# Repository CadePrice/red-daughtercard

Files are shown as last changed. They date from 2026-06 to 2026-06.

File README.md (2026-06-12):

# teensy4.1-daughtercard

* Goal: Connect GigaPCB female connector (XG4H-5031) onto a Teensy 4.1 daughtercard.
* Solution: Use a male connector (XG4A-5034) to link GigaPCB to Teensy 4.1 MCU.

**ALL PLANNING INFORMATION AND PIN WORKS CAN BE FOUND HERE: https://docs.google.com/spreadsheets/d/1IKXbfIiIrP6nyM8Mc0eolMKgb26c2Qc9dl-_x0jVvCI/edit?usp=sharing**

Revisions after Design Review #1 (6/11)
* Added a 3v3 LED to indicate good board connection
* Made TX+/TX- and RX+/RX- differential pairs with matched lengths
* Added GND vias across the board
* Made it a four layer board (signals -> ground -> power -> signals)

Contains the daughtercard housing the Teensy4.1 MCU used for the GIGAPCB architecture for Texas A&amp;M Rocket Engine Design. An Standard Operating Procedure (SOP) will be provided for assembly/use instructions.

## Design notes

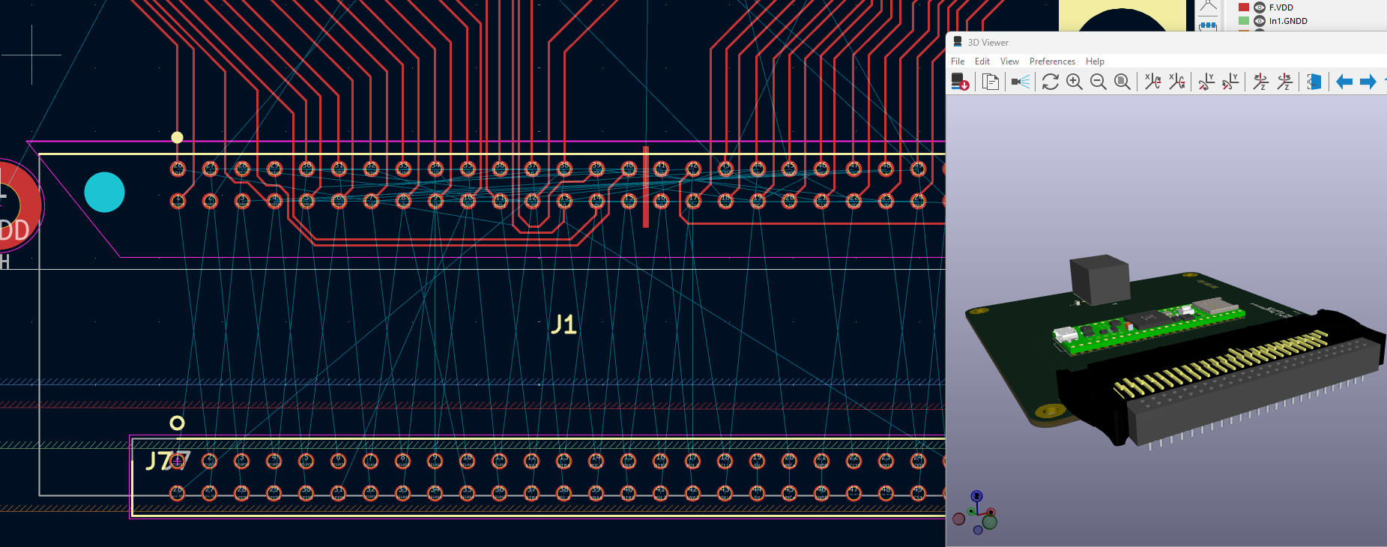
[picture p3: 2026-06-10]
docs/how the connectors will link.png

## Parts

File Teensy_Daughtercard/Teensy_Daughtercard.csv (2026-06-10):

Reference | Qty | Value | DNP | Exclude from BOM | Exclude from Board | Footprint | Datasheet | Mouser Part Number
C1 | 1 | 0.1uF |  |  |  | K104K15X7RF5TL2:K104K15X7RF5TL2 | https://componentsearchengine.com/Datasheets/1/K104K15X7RF5TL2.pdf | 594-K104K15X7RF5TL2
H1,H2,H3,H4 | 4 | MH |  | Excluded from BOM |  | MountingHole:MountingHole_3.5mm_Pad | ~
J1 | 1 | L77HDB44SD1CH4RSAG |  |  |  | L77HDB44SD1CH4RSAG:L77HDB44SD1CH4RSAG | https://componentsearchengine.com/Datasheets/1/L77HDB44SD1CH4RSAG.pdf | 523-L77HDB44SD1CH4RS
J2,J3 | 2 | Conn_01x24_Socket |  |  | Excluded from board |  | https://www.mouser.com/datasheet/3/71/1/M20_782.pdf | 855-M20-7823242
J4,J5 | 2 | Conn_01x24_Pin |  |  | Excluded from board |  | https://cdn.amphenol-cs.com/media/wysiwyg/files/drawing/68000.pdf | 649-68000-124HLF
J6 | 1 | LPJ4012AHNL |  |  |  | LPJ4012AHNL:LPJ4012AHNL | https://www.l-p.com/file/datasheet/lpj4012ahnl-drawing.pdf
U1 | 1 | Teensy4.1 |  |  |  | Teensy:Teensy41

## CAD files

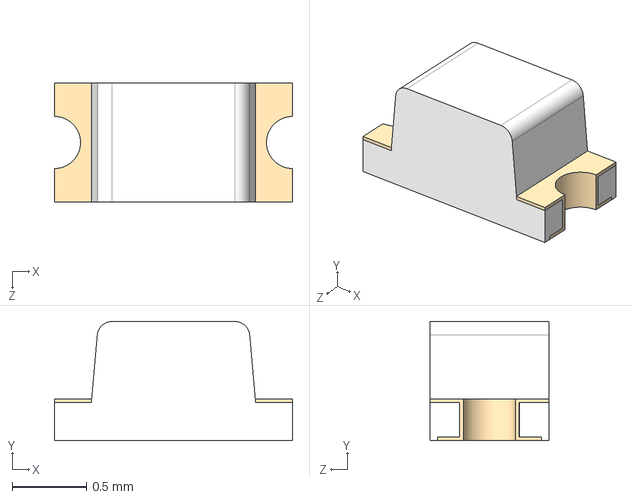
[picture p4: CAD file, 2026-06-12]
Teensy_Daughtercard/Project KiCAD Library/3D Models/LTST-C190YKT.stp
1.60 x 0.8 x 0.8 mm

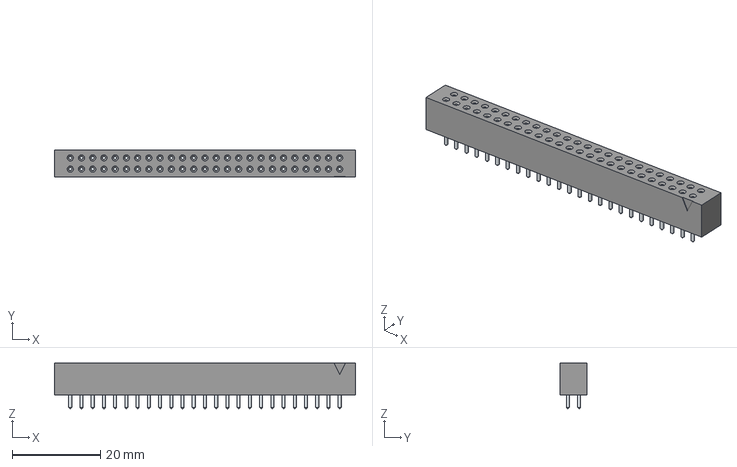
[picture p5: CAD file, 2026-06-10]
Teensy_Daughtercard/Project KiCAD Library/3D Models/XG4H-5031.stp
68.1 x 6.10 x 10.3 mm
LeadsArray

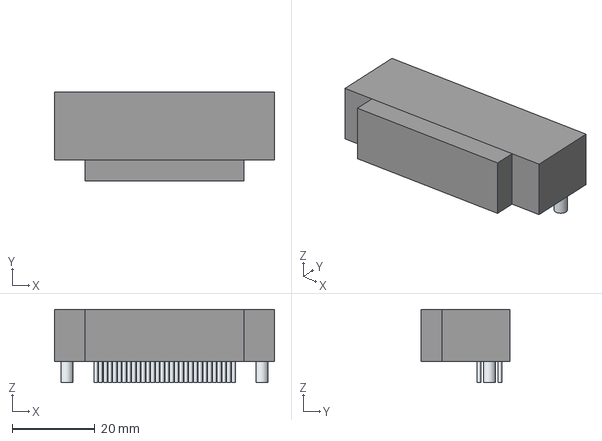
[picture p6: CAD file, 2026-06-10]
Teensy_Daughtercard/Project KiCAD Library/3D Models/L77HDB44SD1CH4RSAG.stp
53.0 x 21.5 x 17.6 mm
Leads x 46

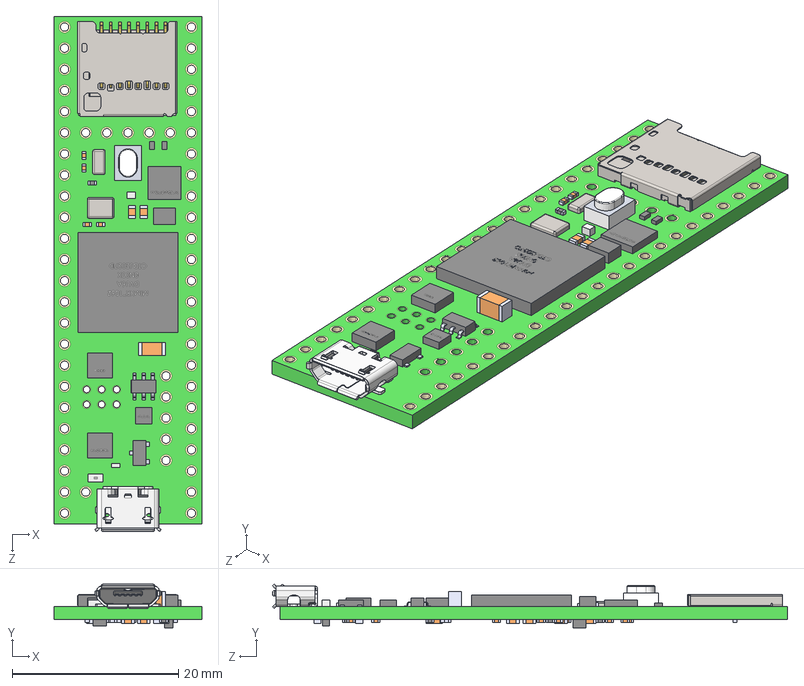
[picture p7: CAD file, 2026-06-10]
Teensy_Daughtercard/Project KiCAD Library/3D Models/Teensy 4.1.STEP
17.8 x 5.26 x 61.9 mm
PCB, Teensy 4.1
SMD Capacitor, Configurable, Teensy 4.1_C8
SMD Capacitor, Configurable, Teensy 4.1_C9
SMD Capacitor, Configurable, Teensy 4.1_C29
SMD Capacitor, Configurable, Teensy 4.1_C13
SMD Capacitor, Configurable, Teensy 4.1_C12
SMD Capacitor, Configurable, Teensy 4.1_C6
SMD Capacitor, Configurable, Teensy 4.1_C5 x 2
SMD Capacitor, Configurable, Teensy 4.1_C11
SMD Capacitor, Configurable, Teensy 4.1_C22
SMD Capacitor, Configurable, Teensy 4.1_C23
SMD Capacitor, Configurable, Teensy 4.1_C14
SMD Capacitor, Configurable, Teensy 4.1_C16
SMD Capacitor, Configurable, Teensy 4.1_C17
SMD Capacitor, Configurable, Teensy 4.1_C20
SMD Capacitor, Configurable, Teensy 4.1_C21
SMD Capacitor, Configurable, Teensy 4.1_C18 x 3
SMD Capacitor, Configurable, Teensy 4.1_C15
SMD Capacitor, Configurable, Teensy 4.1_C10
SMD Capacitor, Configurable, Teensy 4.1_C7
SMD Capacitor, Configurable, Teensy 4.1_C28
SMD Capacitor, Configurable, Teensy 4.1_C27
SMD Capacitor, Configurable, Teensy 4.1_C24
SMD Capacitor, Configurable, Teensy 4.1_C19
SMD Capacitor, Configurable, Teensy 4.1_C25
SMD Capacitor, Configurable, Teensy 4.1_C32
SMD Capacitor, Configurable, Teensy 4.1_C1
SMD Capacitor, Configurable, Teensy 4.1_C2
SMD Capacitor, Configurable, Teensy 4.1_C33
SMD Capacitor, Configurable, Teensy 4.1_C31
SMD Capacitor, Configurable, Teensy 4.1_C30
SMD Resistor, Configurable, Teensy 4.1_R2
SMD Resistor, Configurable, Teensy 4.1_R8
SMD Resistor, Configurable, Teensy 4.1_R3
SMD Resistor, Configurable, Teensy 4.1_R4
SMD Resistor, Configurable, Teensy 4.1_R7
SMD Resistor, Configurable, Teensy 4.1_R6
SMD Resistor, Configurable, Teensy 4.1_R1
SMD Resistor, Configurable, Teensy 4.1_R5
SMD Inductor, Configurable, Teensy 4.1_L1
SMD Inductor, Configurable, Teensy 4.1_L2
SMD Inductor, Configurable, Teensy 4.1_L3
MicroUSB Port, Teensy 4.1
SD Card Slot, Teensy 4.1
Q1, DMG2305UX, Diode, Teensy 4.1
SW1, Tact Switch, Teensy 4.1
U1, MIMXRT1062 DVJ6A 0N00X CTDJ2027D Microcontroller, Teensy 4.1
U2, MKL02Z32VFG4, Teensy 4.1
U3, W25Q64JVXGIM, Teensy 4.1
U4, TLV75733P, Teensy 4.1
U5, TPD3S014, Teensy 4.1
U6, DP83825, Teensy 4.1
Y1, 24 MHz Crystal Resonator, Teensy 4.1
Y2, 32.768 kHz Crystal Resonator, Teensy 4.1
F1, 500 mA Fuse, Teensy 4.1
D4, LED, Teensy 4.1
D3, LED, Teensy 4.1
D1, BAT54C, Teensy 4.1
D2, BAT54C, Teensy 4.1

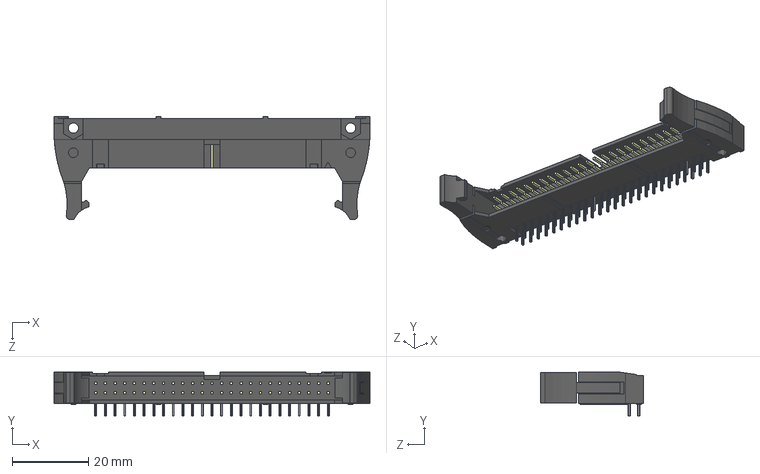
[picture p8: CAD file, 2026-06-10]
Teensy_Daughtercard/Project KiCAD Library/3D Models/XG4A-5034.stp
82.8 x 11.4 x 27.0 mm

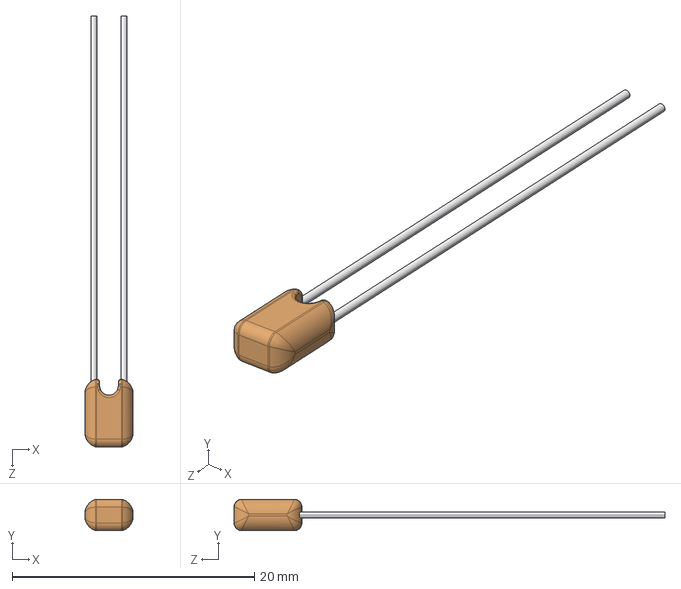
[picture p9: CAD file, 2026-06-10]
Teensy_Daughtercard/Project KiCAD Library/3D Models/K104K15X7RF5TL2.stp
4.00 x 2.60 x 35.6 mm

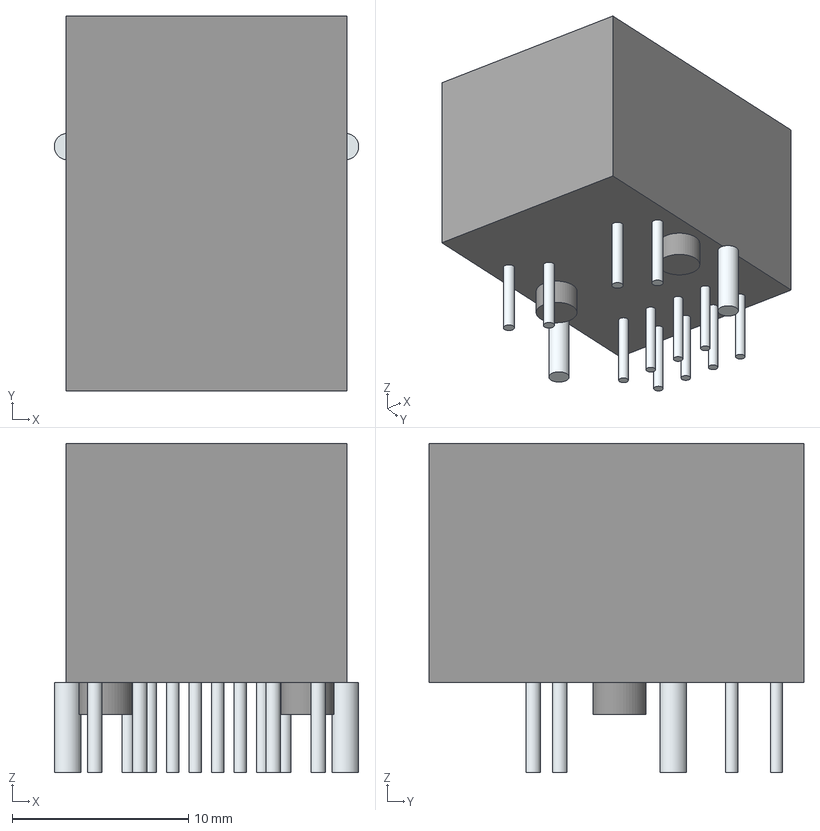
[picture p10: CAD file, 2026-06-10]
Teensy_Daughtercard/Project KiCAD Library/3D Models/LPJ4012AHNL.stp
17.2 x 21.2 x 18.6 mm
Lugs
Leads

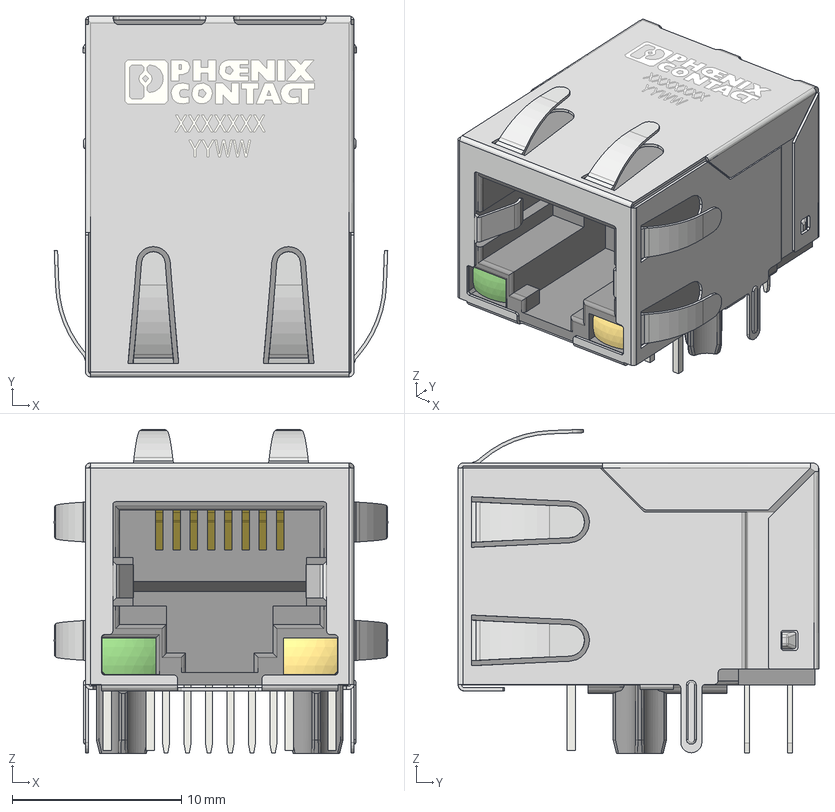
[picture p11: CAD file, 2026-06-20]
Teensy_Daughtercard/Project KiCAD Library/3D Models/1664073.stp
19.7 x 21.4 x 19.2 mm

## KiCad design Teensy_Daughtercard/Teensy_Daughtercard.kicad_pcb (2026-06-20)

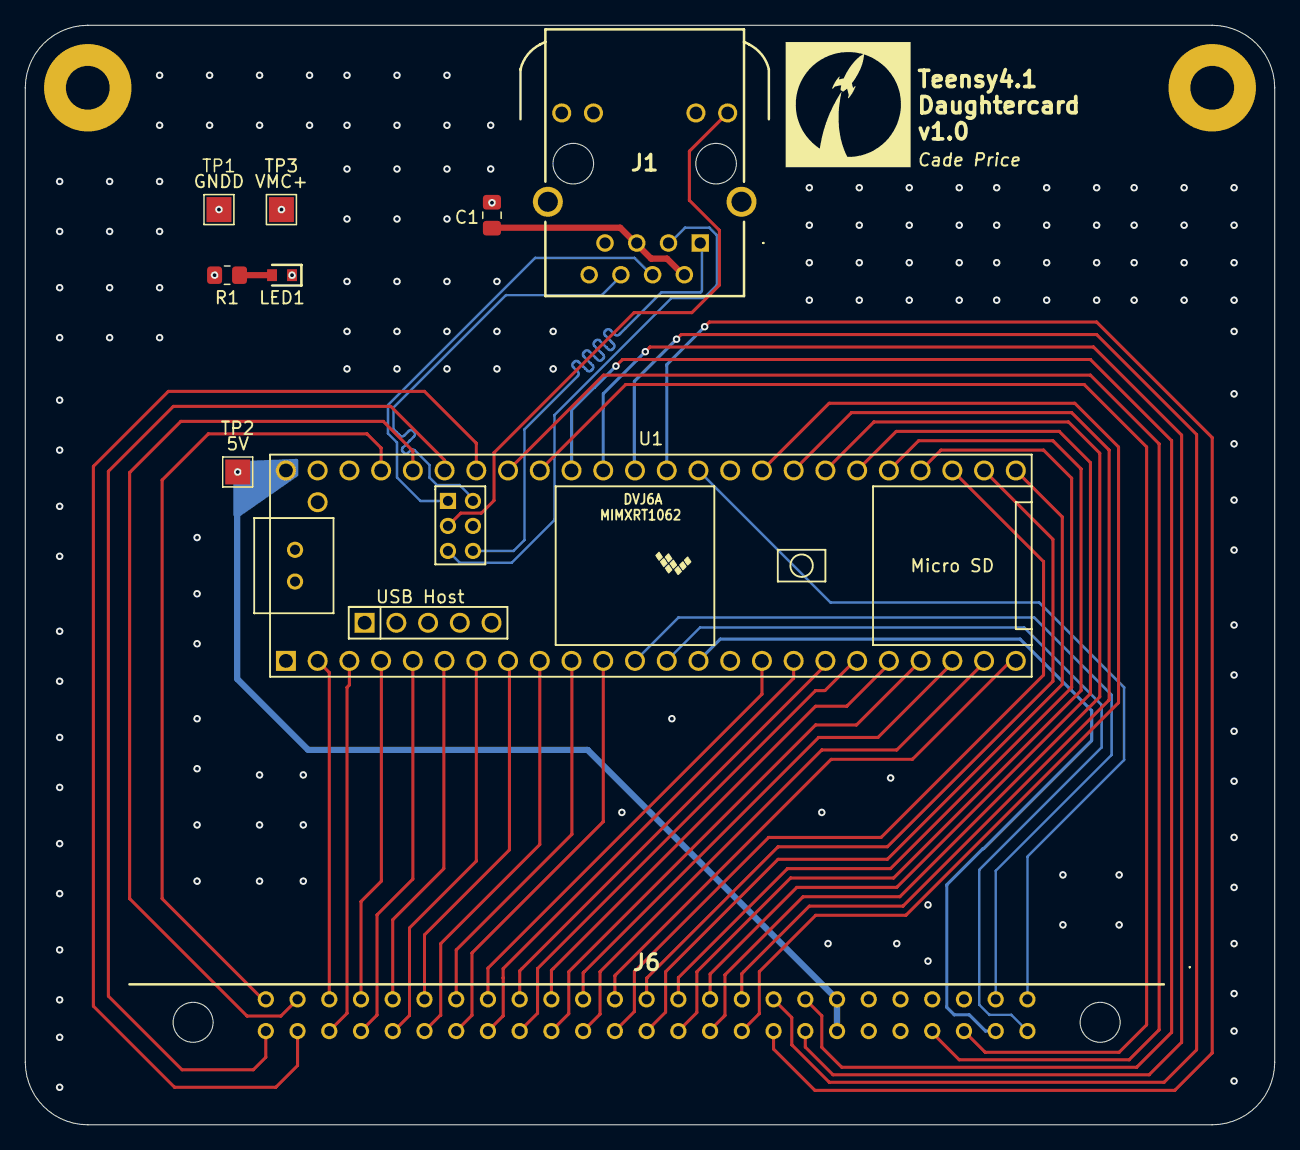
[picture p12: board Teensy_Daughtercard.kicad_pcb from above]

Board: 4 copper layers, 100.0 x 88.0 mm, 11 parts (0 on the bottom side), 52 nets.

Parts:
C1: 0.1uF; C_0805_2012Metric_Pad1.18x1.45mm_HandSolder
H1, H2: MH; MountingHole_3.5mm_Pad
J1: 1664073
J6: XG4A-5034; XG4A5034
LED1: LTST-C190YKT; LEDC1608X90N
R1: 1000; R_0805_2012Metric_Pad1.20x1.40mm_HandSolder
TP1: GND; TestPoint_Pad_2.0x2.0mm
TP2: 5V; TestPoint_Pad_2.0x2.0mm
TP3: VMC+; TestPoint_Pad_2.0x2.0mm
U1: Teensy4.1; Teensy41

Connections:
+5V: J6.19, J6.44, TP2.1 (1_1), U1.48 (VIN)
/CS1: J6.49, U1.12 (10_CS_MQSR)
/DIR1: J6.37, U1.24 (32_OUT1B)
/DIR2: J6.16, U1.33 (41_A17)
/DIR3: J6.40, U1.30 (38_CS1_IN1)
/DIR4: J6.13, U1.25 (33_MCLK2)
/ENA1: J6.12, U1.27 (35_TX8)
/ENA2: J6.42, U1.37 (15_A1_RX3_SPDIF_IN)
/ENA3: J6.15, U1.31 (39_MISO1_OUT1A)
/ENA4: J6.39, U1.28 (36_CS)
/ETH_LED: J1.P11 (A_GREEN), U1.61 (LED)
/ETH_RX+: J1.P4 (RD+), U1.60 (R+)
/ETH_RX-: J1.P6 (RD-), U1.65 (R-)
/ETH_TX+: J1.P1 (TD+), U1.63 (T+)
/ETH_TX-: J1.P3 (TD-), U1.62 (T-)
/GPIO1: J6.28, U1.2 (0_RX1_CRX2_CS1)
/GPIO2: J6.29, U1.4 (2_OUT2)
/GPIO3: J6.30, U1.6 (4_BCLK2)
/GPIO4: J6.31, U1.8 (6_OUT1D)
/Imon PS1: J6.26, U1.45 (23_A9_CRX1_MCLK1)
/Imon PS2: J6.27, U1.44 (22_A8_CTX1)
/PUL1: J6.38, U1.26 (34_RX8)
/PUL2: J6.17, U1.36 (14_A0_TX3_SPDIF_OUT)
/PUL3: J6.41, U1.32 (40_A16)
/PUL4: J6.14, U1.29 (37_CS)
/RELAY1: J6.11, U1.23 (31_CTX3)
/RELAY2: J6.36, U1.22 (30_CRX3)
/RELAY3: J6.10, U1.21 (29_TX7)
/RELAY4: J6.35, U1.20 (28_RX7)
/RELAY5: J6.9, U1.19 (27_A13_SCK1)
/RELAY6: J6.34, U1.18 (26_A12_MOSI1)
/RELAY7: J6.33, U1.16 (24_A10_TX6_SCL2)
/RELAY8: J6.8, U1.17 (25_A11_RX6_SDA2)
/RELAY9: J6.7, U1.11 (9_OUT1C)
/RELAY10: J6.32, U1.10 (8_TX2_IN1)
/RELAY11: J6.6, U1.9 (7_RX2_OUT1A)
/RELAY12: J6.5, U1.7 (5_IN2)
/RELAY13: J6.4, U1.5 (3_LRCLK2)
/RELAY14: J6.3, U1.3 (1_TX1_CTX2_MISO1)
/RELAY15: J6.1, U1.43 (21_A7_RX5_BCLK1)
/RELAY16: J6.2, U1.42 (20_A6_TX5_LRCLK1)
/SCLK1: J6.50, U1.35 (13_SCK_LED)
/SCLLC: J6.18, U1.38 (16_A2_RX4_SCL1)
/SCLTC: J6.22, U1.41 (19_A5_SCL)
/SDALC: J6.43, U1.39 (17_A3_TX4_SDA1)
/SDATC: J6.23, U1.40 (18_A4_SDA)
/SDI1: J6.25, U1.13 (11_MOSI_CTX1)
/SDO1: J6.24, U1.14 (12_MISO_MQSL)
GNDD: C1.1, H1.1 (1_1), H2.1 (1_1), J1.P8 (CHS_GROUND), J1.P12 (K_GREEN), J6.21, J6.46, LED1.1 (K), TP1.1 (1_1), U1.1 (GND), U1.34 (GND), U1.47 (GND), U1.64 (GND)
unnamed: C1.2, J1.P2 (TCT), J1.P5 (RCT)
unnamed: LED1.2 (A), R1.1
VMC+: J6.20, J6.45, R1.2, TP3.1 (1_1), U1.15 (3V3), U1.46 (3V3)

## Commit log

2026-06-10 WIP 6/9/26
    [K104K15X7RF5TL2.stp, L77HDB44SD1CH4RSAG.stp, LPJ4012AHNL.stp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]
2026-06-11 First draft complete
    [Teensy_Daughtercard.kicad_pcb, Teensy_Daughtercard.kicad_sch]
2026-06-11 First revision 6/11
    [LTST-C190YKT.stp, Teensy_Daughtercard.kicad_pcb, Teensy_Daughtercard.kicad_sch]
2026-06-18 Replaced Magjack
    [1664073.stp, Teensy_Daughtercard.kicad_pcb, Teensy_Daughtercard.kicad_sch]
2026-06-20 Final changes
    [Teensy_Daughtercard-B_Cu.gbl, Teensy_Daughtercard-B_Mask.gbs, Teensy_Daughtercard-B_Paste.gbp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]
